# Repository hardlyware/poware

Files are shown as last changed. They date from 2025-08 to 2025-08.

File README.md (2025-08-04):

# PoWARE⚡

PoWARE is a handy breadboard power supply for the modern maker & engineer. 
 - 🔌 USB-C PD powered
 - ⚙️ Adjustable rail voltages: 3V3–5V
 - 🪛 Screw terminal for direct PD access: 5–20V

<p align="center">
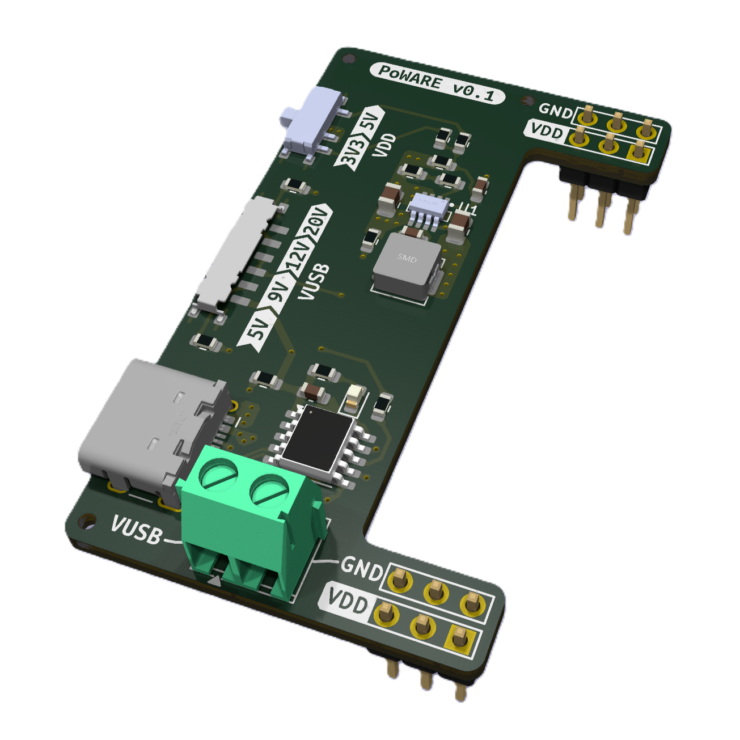
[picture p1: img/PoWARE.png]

</p>

## How do I get one?
PoWARE will be available on Tindie when finished. If you're interested, please let me know by e-mail or contacting me on any of my socials.

## Licenses
PoWARE hardware is licensed under CERN-OHL-S-2.0. See LICENSE file.

## 📬 Get in Touch

- 📧 **Email**: [info@hardlyware.com](mailto:info@hardlyware.com)
- 📸 **Instagram**: [@hardlyware](https://www.instagram.com/hardlyware/)
- 🎥 **YouTube**: [HARDlyWARE](hhttps://www.youtube.com/@HARDlyWARE)

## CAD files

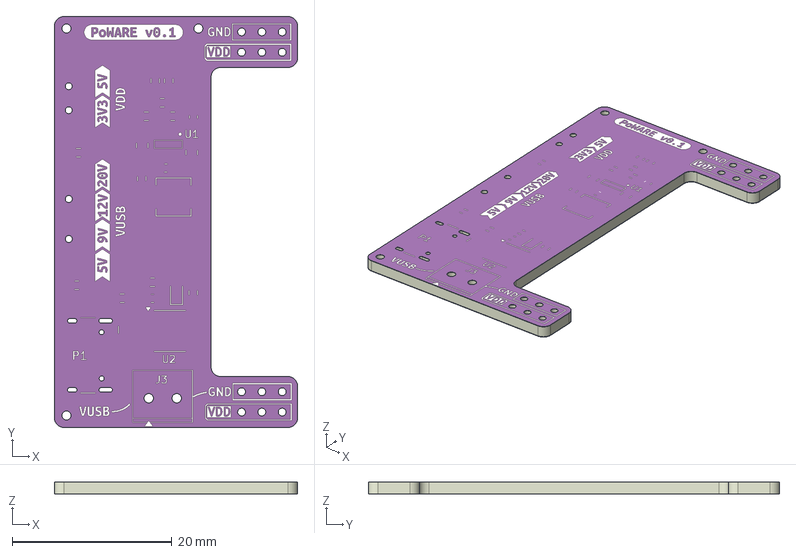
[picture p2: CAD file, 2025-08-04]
PoWARE_v0.1_3D.step
30.4 x 51.4 x 1.67 mm
PoWARE_wo_jumpers_silkscreen
PoWARE_wo_jumpers_soldermask
PoWARE_wo_jumpers_PCB

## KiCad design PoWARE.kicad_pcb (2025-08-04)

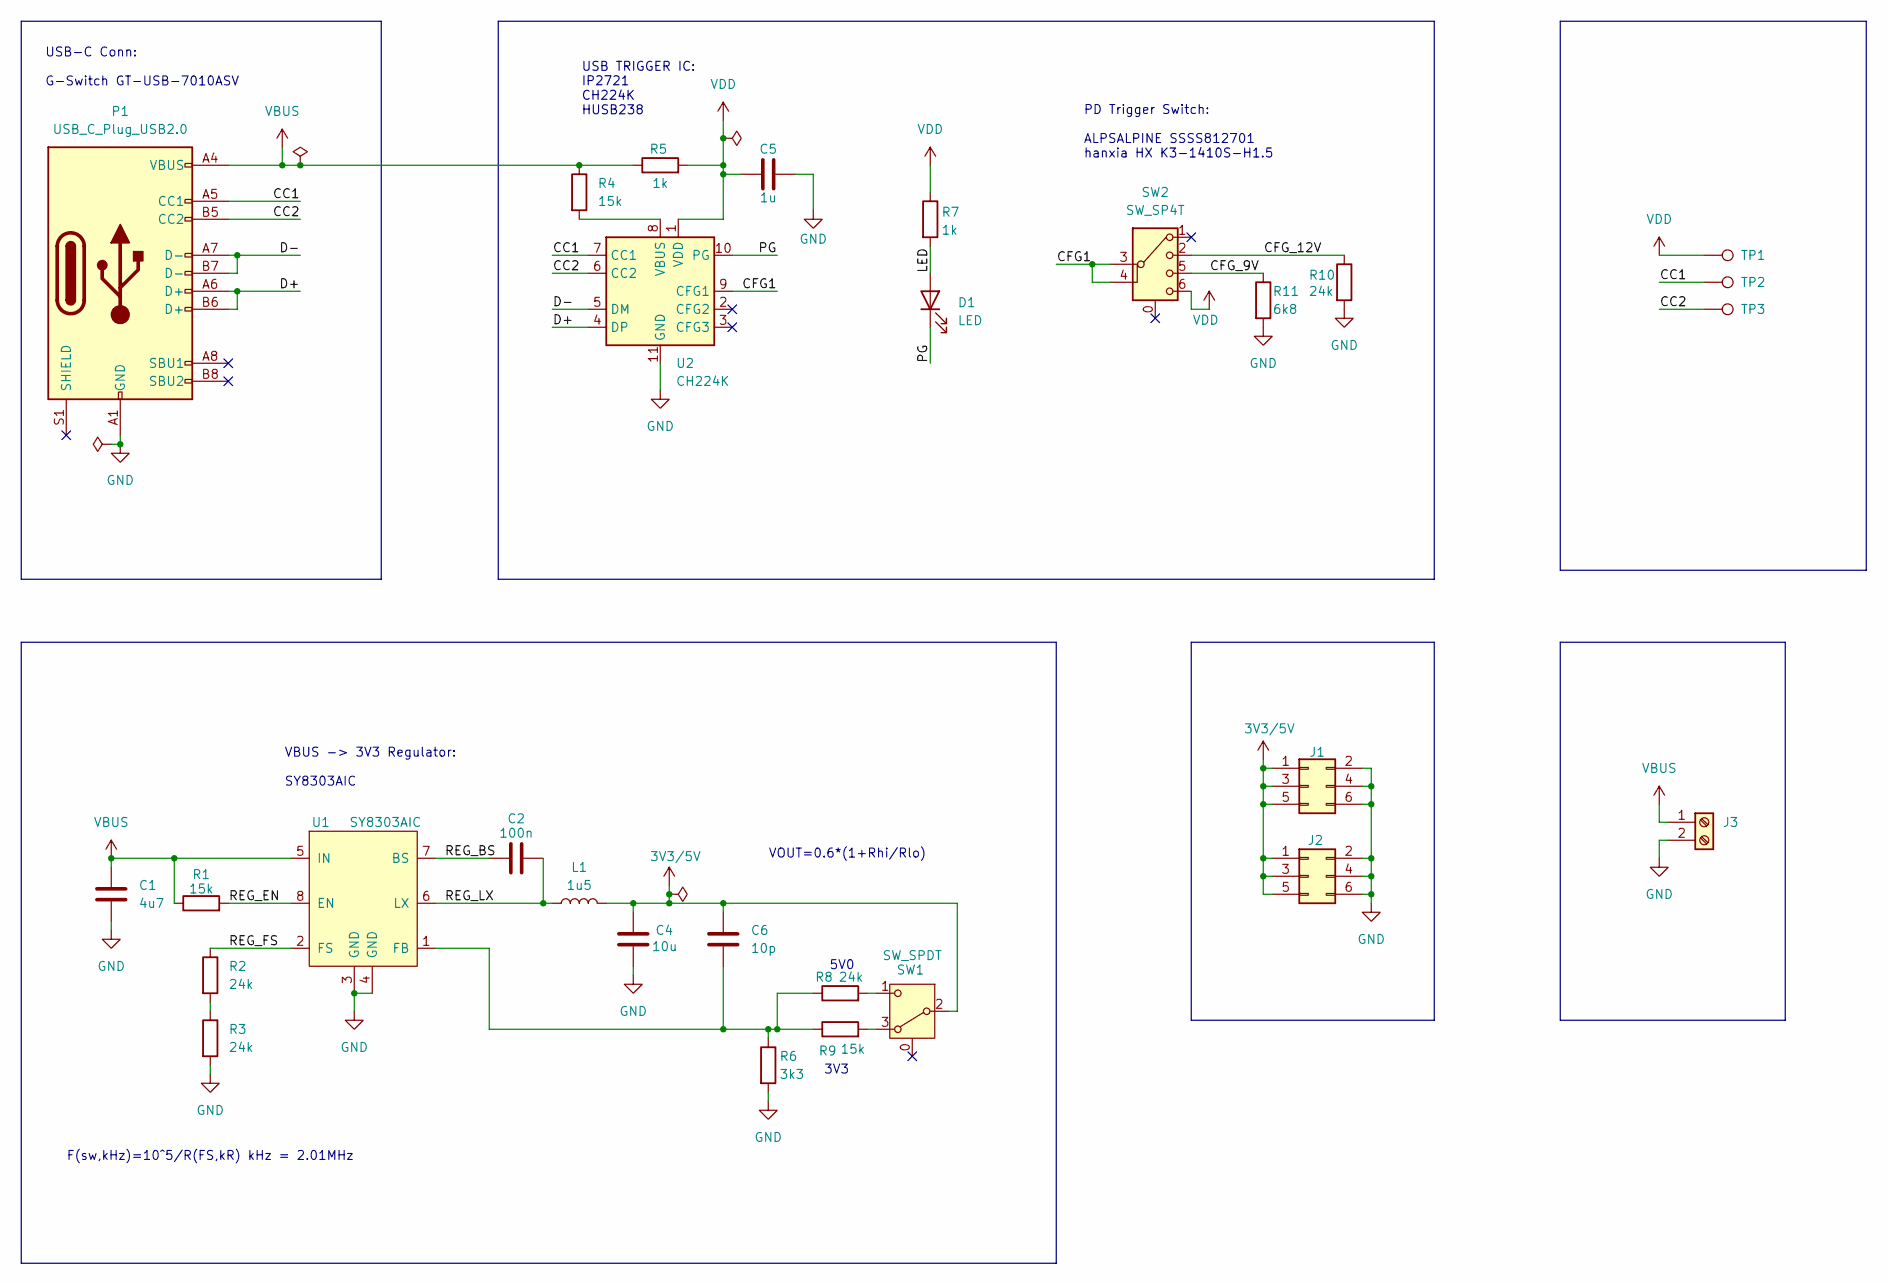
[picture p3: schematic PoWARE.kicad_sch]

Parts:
C1: 4u7; C_0805_2012Metric
C2: 100n; C_0603_1608Metric
C4: 10u; C_0805_2012Metric
C5: 1u; C_0603_1608Metric
C6: 10p; C_0603_1608Metric
D1: LED; LED_0603_1608Metric
J1, J2: Conn_02x03_Counter_Clockwise; PinHeader_2x03_P2.54mm_Vertical
J3: Screw_Terminal_01x02; DB301V-3.5-2P-GN-S
L1: 1u5; FXL0420-1R5-M
P1: USB_C_Plug_USB2.0; USB_C_Receptacle_HCTL_HC-TYPE-C-16P-01A
R1, R4, R9: 15k; R_0603_1608Metric
R2, R3, R8, R10: 24k; R_0603_1608Metric
R5, R7: 1k; R_0603_1608Metric
R6: 3k3; R_0603_1608Metric
R11: 6k8; R_0603_1608Metric
SW1: SW_SPDT; SSSS811101
SW2: SW_SP4T; SSSS812701
TP1, TP2, TP3: TestPoint; TestPoint_Pad_D1.0mm
U1: SY8303AIC
U2: CH224K; CH224K-SSOP-10-1EP

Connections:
3V3/5V: C4.1, C6.2, J1.1, J1.3, J1.5, J2.1, J2.3, J2.5, L1.2, SW1.2 (B)
/CC1: P1.A5 (CC1), TP2.1, U2.7 (CC1)
/CC2: P1.B5 (CC2), TP3.1, U2.6 (CC2)
/CFG1: SW2.3, SW2.4, U2.9 (CFG1)
/CFG_9V: R11.1, SW2.5
/CFG_12V: R10.1, SW2.2
/D+: P1.A6 (D+), P1.B6 (D+), U2.4 (DP)
/D-: P1.A7 (D-), P1.B7 (D-), U2.5 (DM)
/LED: D1.2 (A), R7.2
/PG: D1.1 (K), U2.10 (PG)
/REG_BS: C2.1, U1.7 (BS)
/REG_EN: R1.2, U1.8 (EN)
/REG_FS: R2.1, U1.2 (FS)
/REG_LX: C2.2, L1.1, U1.6 (LX)
GND: C1.2, C4.2, C5.2, J1.2, J1.4, J1.6, J2.2, J2.4, J2.6, J3.2, P1.A1 (GND), P1.A12 (GND), P1.B1 (GND), P1.B12 (GND), R3.2, R6.2, R10.2, R11.2, U1.3 (GND), U1.4 (GND), U2.11 (GND)
unnamed: R2.2, R3.1
unnamed: R8.2, SW1.1 (A)
unnamed: R9.2, SW1.3 (C)
unnamed: C6.1, R6.1, R8.1, R9.1, U1.1 (FB)
unnamed: R4.2, U2.8 (VBUS)
VBUS: C1.1, J3.1, P1.A4 (VBUS), P1.A9 (VBUS), P1.B4 (VBUS), P1.B9 (VBUS), R1.1, R4.1, R5.1, U1.5 (IN)
VDD: C5.1, R5.2, R7.1, SW2.6, TP1.1, U2.1 (VDD)

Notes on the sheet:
F(sw,kHz)=10^5/R(FS,kR) kHz = 2.01MHz
3V3
5V0
VBUS -> 3V3 Regulator: SY8303AIC
USB TRIGGER IC: IP2721 CH224K HUSB238
VOUT=0.6*(1+Rhi/Rlo)
USB-C Conn: G-Switch GT-USB-7010ASV
PD Trigger Switch: ALPSALPINE SSSS812701 hanxia HX K3-1410S-H1.5

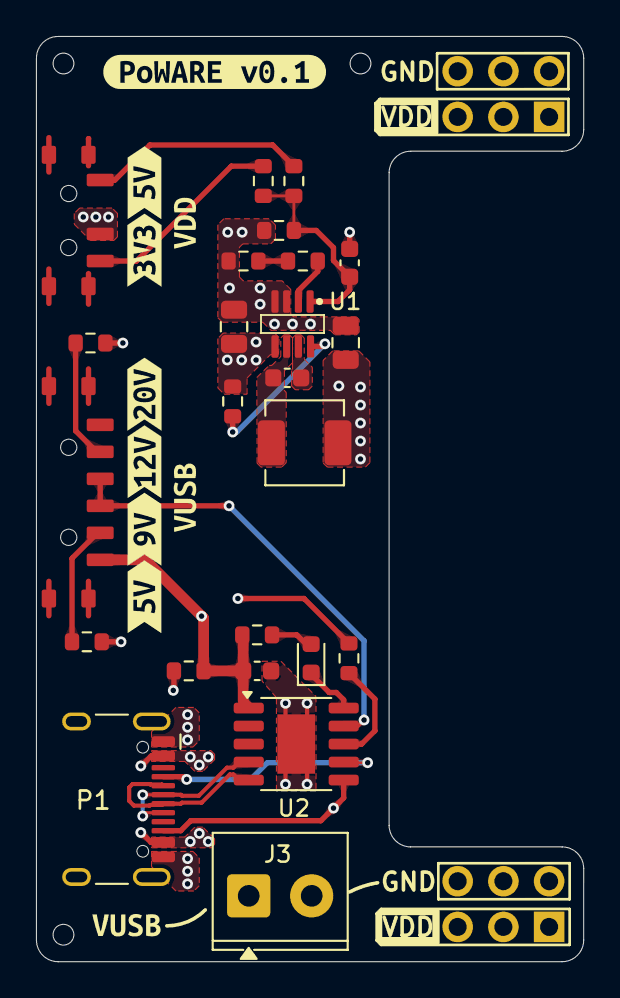
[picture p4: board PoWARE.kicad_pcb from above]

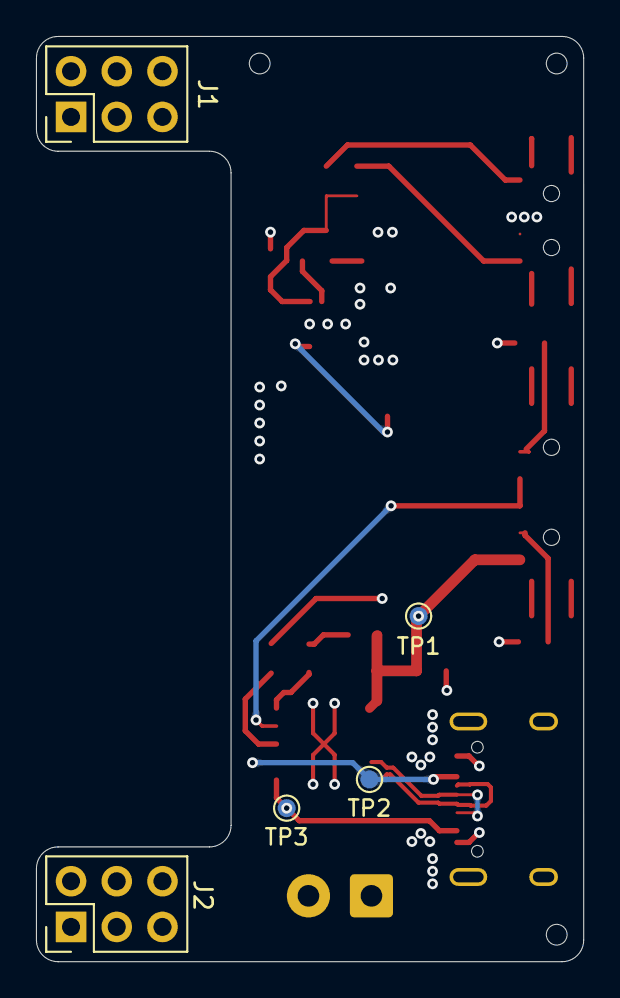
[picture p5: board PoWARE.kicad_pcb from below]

Board: 4 copper layers, 30.4 x 51.4 mm, 39 parts (5 on the bottom side), 22 nets.

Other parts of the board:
kibuzzard-68873AFF: G***; kibuzzard-68873AFF
kibuzzard-68873B0E: G***; kibuzzard-68873B0E
kibuzzard-68873B1A: G***; kibuzzard-68873B1A
kibuzzard-68873B2C: G***; kibuzzard-68873B2C
kibuzzard-68873B06: G***; kibuzzard-68873B06
kibuzzard-68873B23: G***; kibuzzard-68873B23
kibuzzard-68873D2B: G***; kibuzzard-68873D2B
kibuzzard-68873D34, kibuzzard-68873D34#2: G***; kibuzzard-68873D34
kibuzzard-6887416B: G***; kibuzzard-6887416B

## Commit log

2025-07-30 Initial commit v0.1
    [PoWARE.kicad_pcb, PoWARE.kicad_sch, PoWARE_wo_jumpers.kicad_pcb]
2025-08-04 Small change to jumperless kicad design files
    [PoWARE_wo_jumpers.kicad_pcb]
2025-08-04 Cleaned up repo
    [PoWARE.kicad_pcb, PoWARE.kicad_sch, PoWARE_v0.1_3D.step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]
